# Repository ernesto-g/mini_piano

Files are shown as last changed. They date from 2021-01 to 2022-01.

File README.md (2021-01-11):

# Mini piano

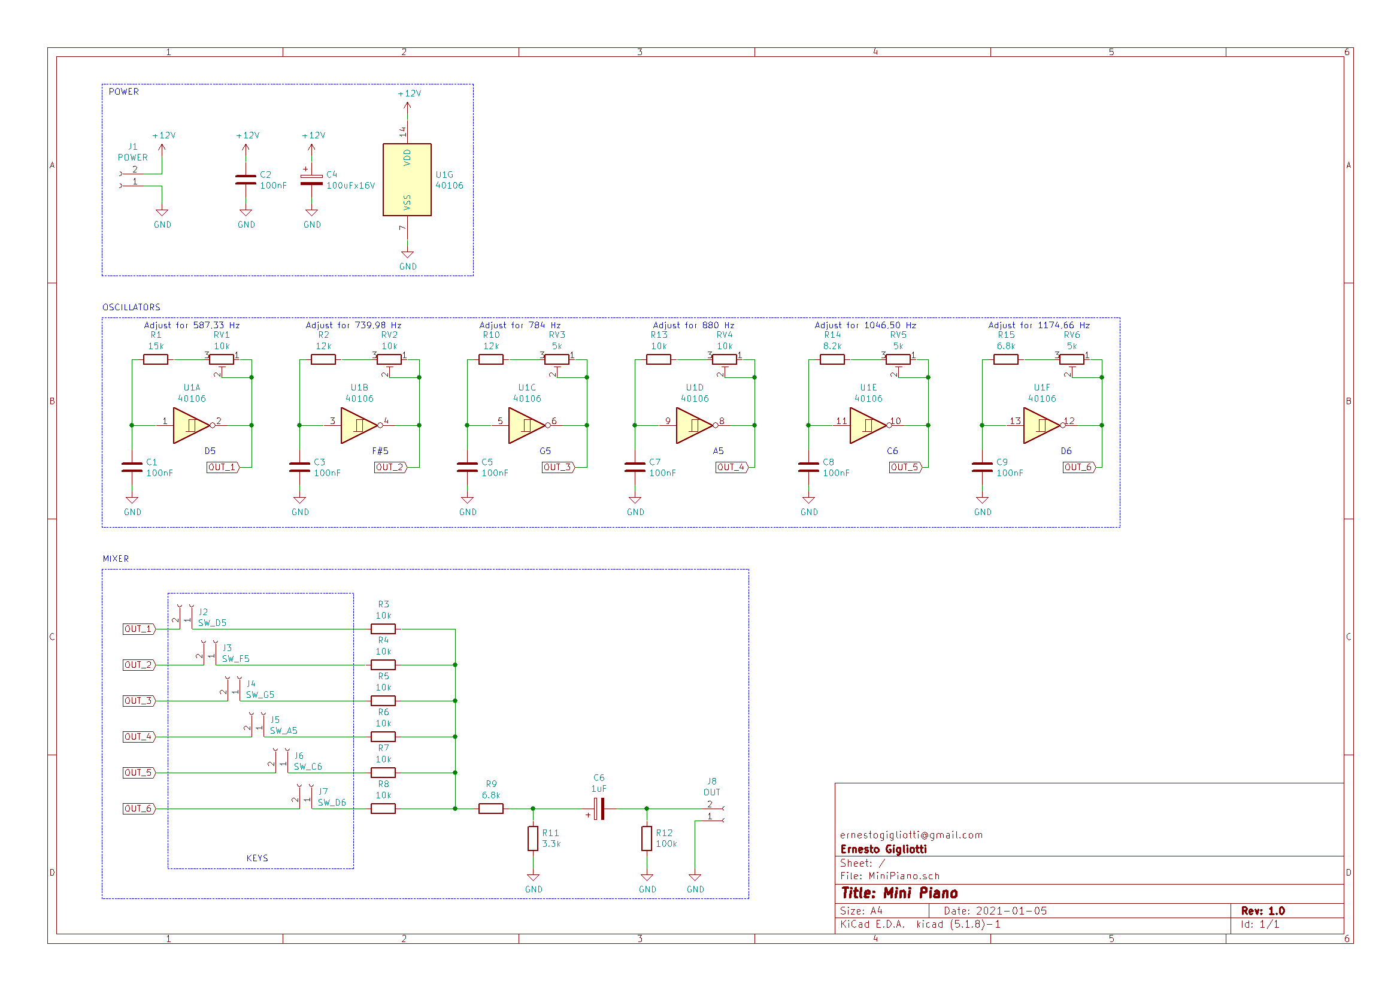
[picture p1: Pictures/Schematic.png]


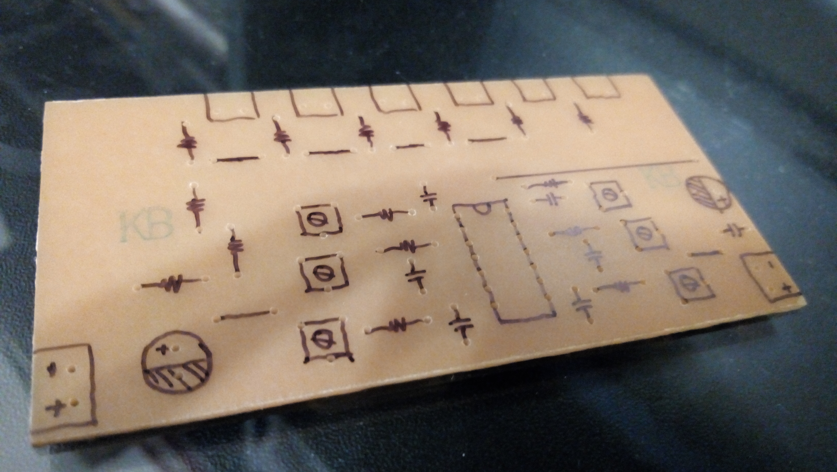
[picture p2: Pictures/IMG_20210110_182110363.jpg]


Characteristics:

  - six-note keyboard
  - D major pentatonic scale
  - 12V power input

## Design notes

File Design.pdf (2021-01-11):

Trabajo Practico: Piano con escala pentatónica

Diseñar un piano con 5 notas pertenecientes a la escala pentatónica. La forma de onda del sonido debe ser una señal cuadrada con un nivel de audio de línea. Se deberá utilizar el circuito integrado 40106 el cual consta de 6 negadores, y para la alimentación una batería de 9V.

Pasos a seguir

a) Definir las notas que tendrá el piano según la escala pentatónica y la nota raíz elegida.
b) Según la tabla de frecuencias link: https://en.wikipedia.org/wiki/Piano_key_frequencies obtener las 5 frecuencias correspondientes a las notas elegidas.
c) Plantear usar un capacitor de 1uF (1 dividido 1 millon) y calcular el valor exacto de las resistencias para los 5 casos.
d) Según los valores de R calculados, seleccionar un valor de resistencia estándar y agregarle una resistencia variable en serie para ajustar el valor de cada nota.

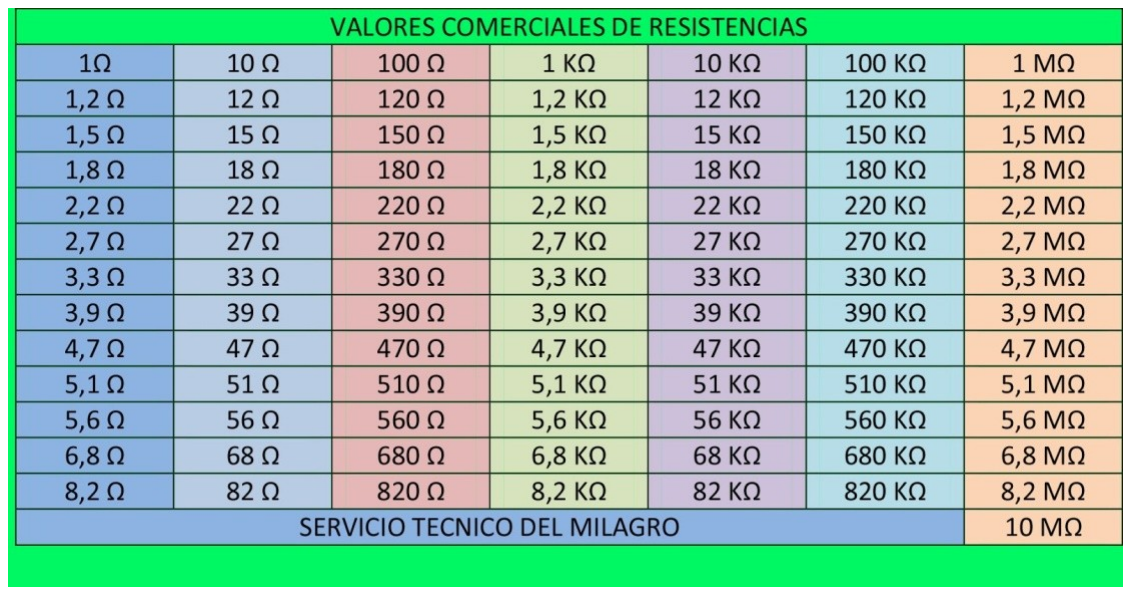
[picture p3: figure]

Los valores estándar de las resistencias variables son:

100ohm, 250ohm, 500ohm, 1K, 2.5K, 5K,10K,25K,50K,100K

e) Agregar los pulsadores (teclas) al circuito
f) Agregar circuito sumador, para poder sumar la salida de los 5 osciladores
g) Agregar el circuito para adaptar el nivel de señal a una salida de linea (1,41V )

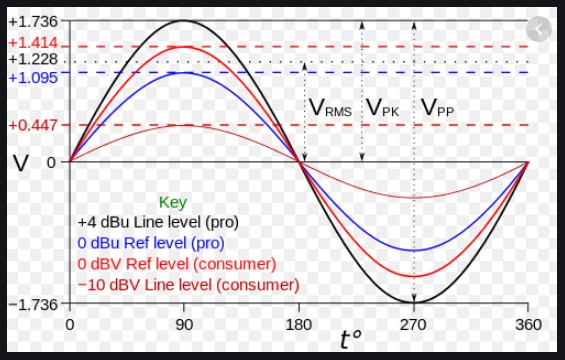
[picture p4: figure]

h) Simular circuito utilizando Proteus 8
i) Armar circuito:
1. Definir lista de componentes
2. Definir alimentación a utilizar

Resolución

1) Elección de la escala y frecuencias: Re Pentatónica
Nota | Frecuencia
D5 | 587,33 Hz
F#5 | 739,98 Hz
G5 | 784 Hz
A5 | 880 Hz
C6 | 1046,50 Hz
D6 | 1174,66 Hz
2) Calculos de resistencias suponiendo capacitor de 100nF (0,1uF)

R=

1,2
f ∗ 100 nF

RD5=

1,2
587,33Hz ∗ 100 nF

=20431,44 ohm

RF5=

1,2
739,98Hz ∗ 100 nF

=16.216,216 ohm ≈ 16 k

RG5=

1,2
784 Hz ∗ 100nF

=15306,12 ohm≈ 15k

RA 5=

1,2
880 Hz ∗ 100 nF

=13636,36 ohm≈ 14 k

RC 6=

1,2
1046,50 Hz ∗100 nF

=11466,80ohm≈ 11k

RD6=

1,2
1174,66 Hz∗100 nF

=10215,72 ohm≈ 10 k

Nota | Resistencia justa
D5 | 20K
F#5 | 16K
G5 | 15K
A5 | 14K
C6 | 11K
D6 | 10K
3) Calculamos el valor estándar de la resistencia junto a la resistencia variable para calibrar

Calculo para D5

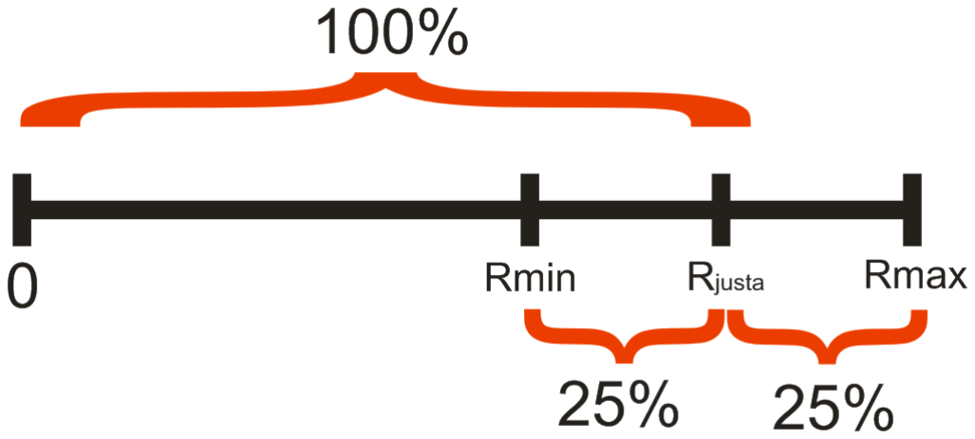
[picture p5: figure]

RD5−min=75% Rjusta=0,75∗20 K=15K

RD5−max=125 % Rjusta=1,25∗20 K=25 K

RD5−fija=RD5−min=15 k

RD5−variable=RD5−max− RD 5− min=25k −15k=10K

Calculo para F#5

RF5−min=75% Rjusta=0,75∗16 K=12K

RF5−max=125% Rjusta=1,25∗16 K=22K

RF5−fija=RF5−min=12 K

RF5−variable=RF5− max− RF5−min=22k −12 k=10 K

Calculo para G5

RG5− min=75% Rjusta=0,75∗ 15K=12K

RG5− max=125% Rjusta=1,25∗15 K=18K

RG5−fija=RG5− min=12K

RG5−variable=RG5−max−RG5−min=18 k −12 k=5 K

Calculo para A5

RA 5− min=75% Rjusta=0,75∗ 14 K=10 K

RA 5− max=125 % Rjusta=1,25∗ 14 K=18 K

RG5−fija=RG5− min=12K

RA 5−variable=RA5−max− RA5− min=18k −10 k=10 K

Calculo para C6

RC 6− min=75% Rjusta=0,75∗ 11K=8,2 K

RC 6− max=125% Rjusta=1,25∗11 K=14 K

RC 6−fija=RC 6− min=8,2K

RC 6−variable=RC6− max−RC6− min=14 k −8,2 k=5 K

Calculo para D6

RD6−min=75% Rjusta=0,75∗10 K=6,8 K

RD6−max=125 % Rjusta=1,25∗10 K=12,5 K

RD6−fija=RD6−min=6,8 K

RD6−variable=RD6− max−RD6−min=12,5 k −6,8 k=5 K

Resumen

Nota | R fija | R variable
D5 | 15K | 10K
F#5 | 12K | 10K
G5 | 12K | 5K
A5 | 10K | 10K
C6 | 8,2K | 5K
D6 | 6,8K | 5K

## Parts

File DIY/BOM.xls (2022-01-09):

Componente | Valor | Cantidad | Comentarios
> C1-C3, C5, C7-C9 | 100nF | 7
C4 | 100uFx16V | 1
C6 | 1uF | 1
J1 | POWER | 1 | PLUG HEMBRA
J2 | SW_D5 | 1
J3 | SW_F5 | 1
J4 | SW_G5 | 1
J5 | SW_A5 | 1
J6 | SW_C6 | 1
J7 | SW_D6 | 1
J8 | OUT | 1 | RCA, NO HAY JACK
R1 | 15k | 1
R2 | 12k | 1
R9 | 6.8k | 1
R10 | 18k | 1
R11 | 470 | 1
R12 | 100k | 1
> R3-R8, R13, R14 | 10k | 8
R15 | 8.2k | 1
> RV1, RV2, RV4 | 10k | 3 | NO HAY, PONEMOS 50K
> RV3, RV5, RV6 | 5k | 3
U1 | 40106 | 1
 |  |  | Si se usa RV1,RV2 y RV4 de 50K,
 |  |  | Puentear R1,R2 y R13

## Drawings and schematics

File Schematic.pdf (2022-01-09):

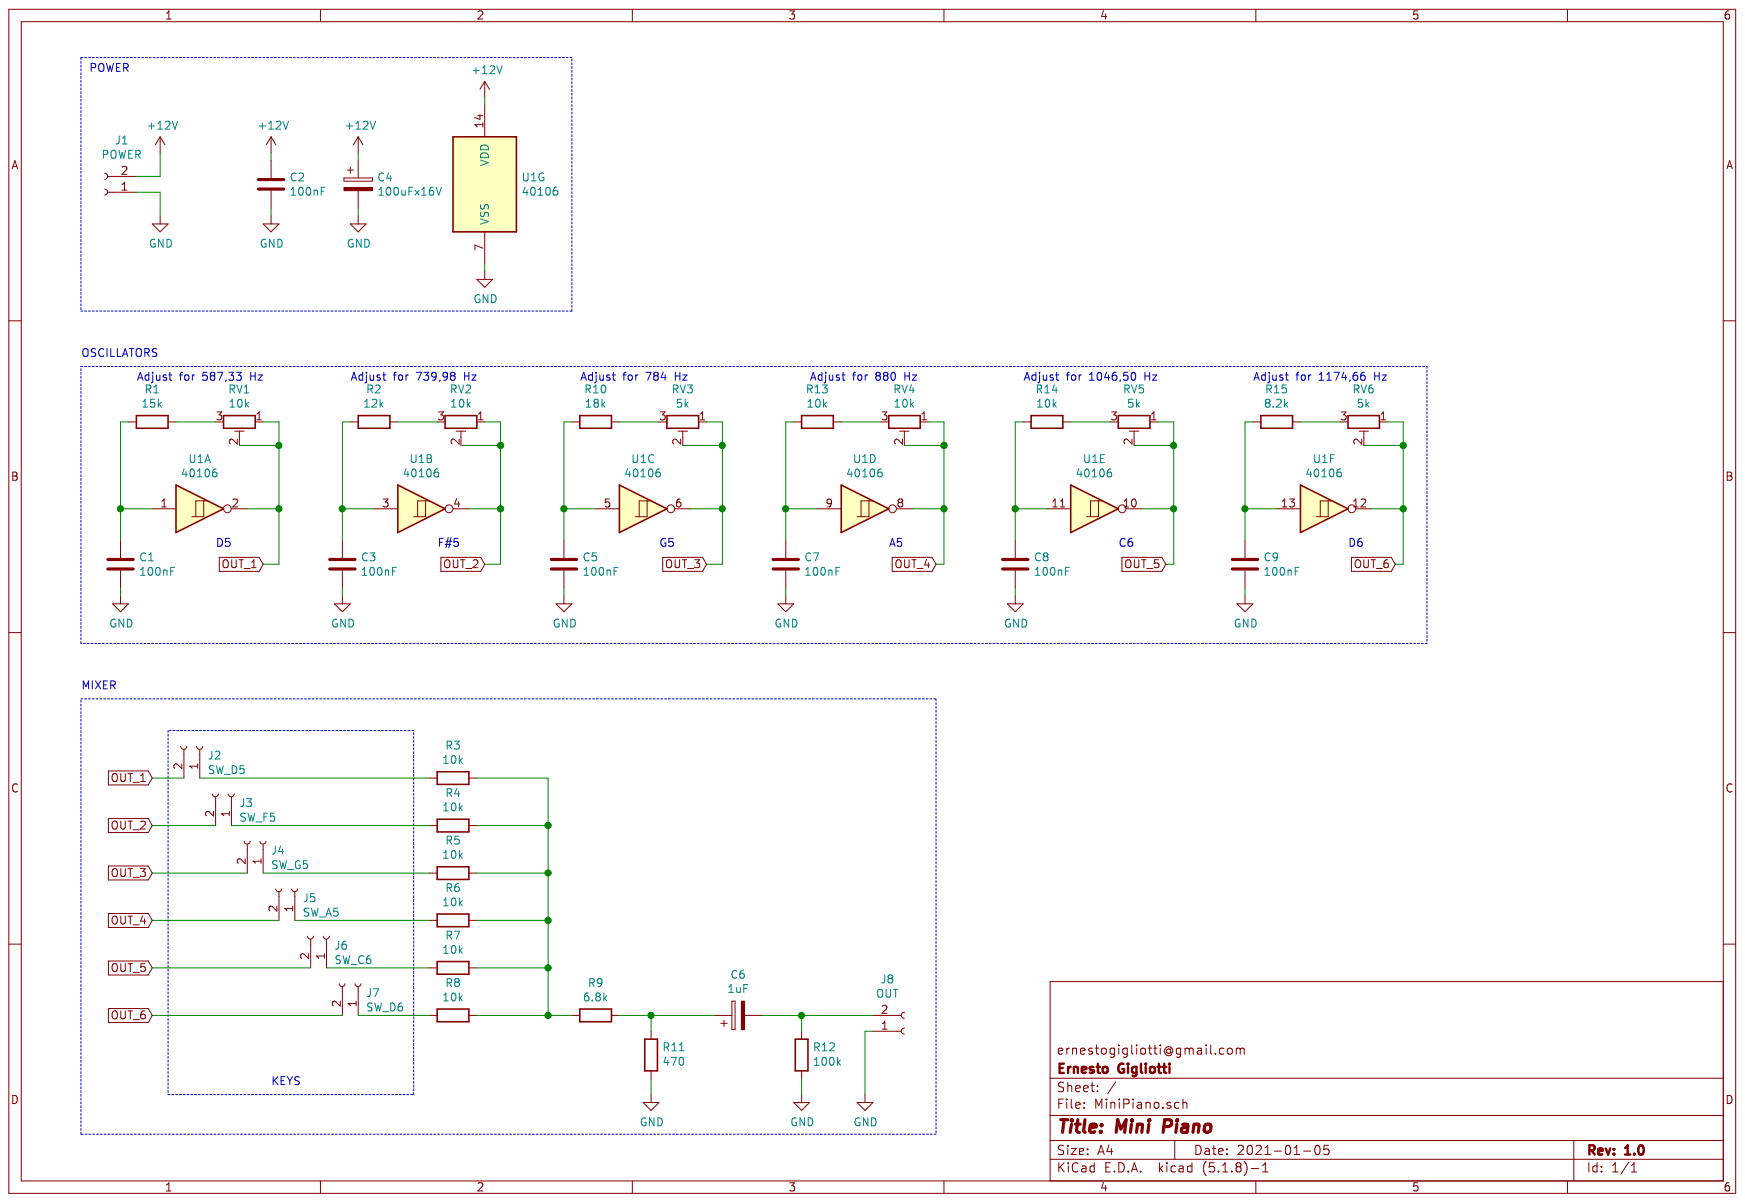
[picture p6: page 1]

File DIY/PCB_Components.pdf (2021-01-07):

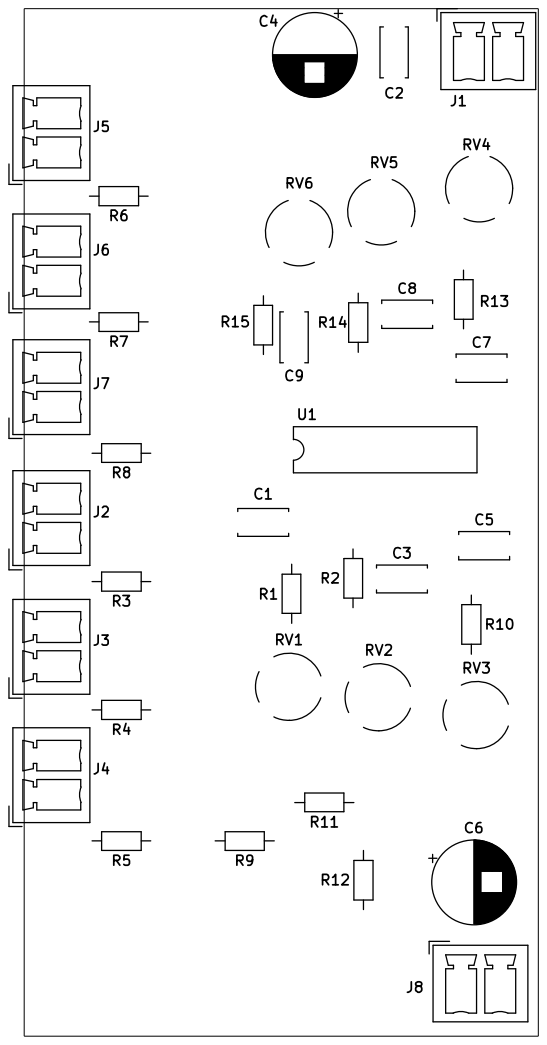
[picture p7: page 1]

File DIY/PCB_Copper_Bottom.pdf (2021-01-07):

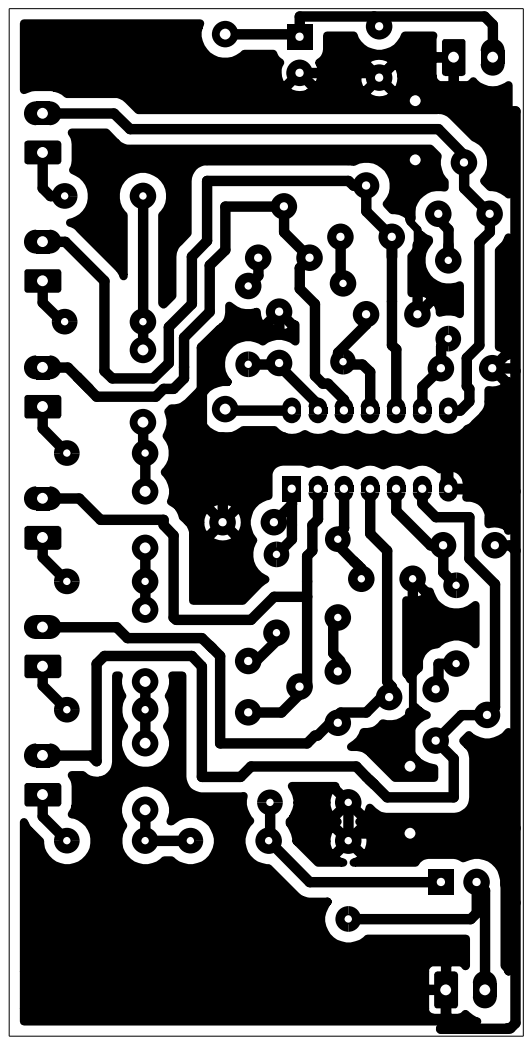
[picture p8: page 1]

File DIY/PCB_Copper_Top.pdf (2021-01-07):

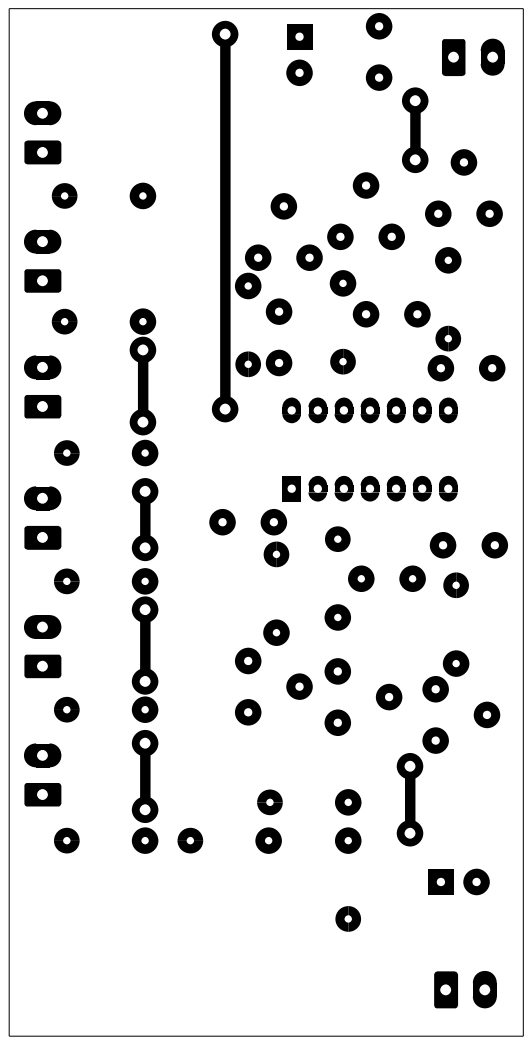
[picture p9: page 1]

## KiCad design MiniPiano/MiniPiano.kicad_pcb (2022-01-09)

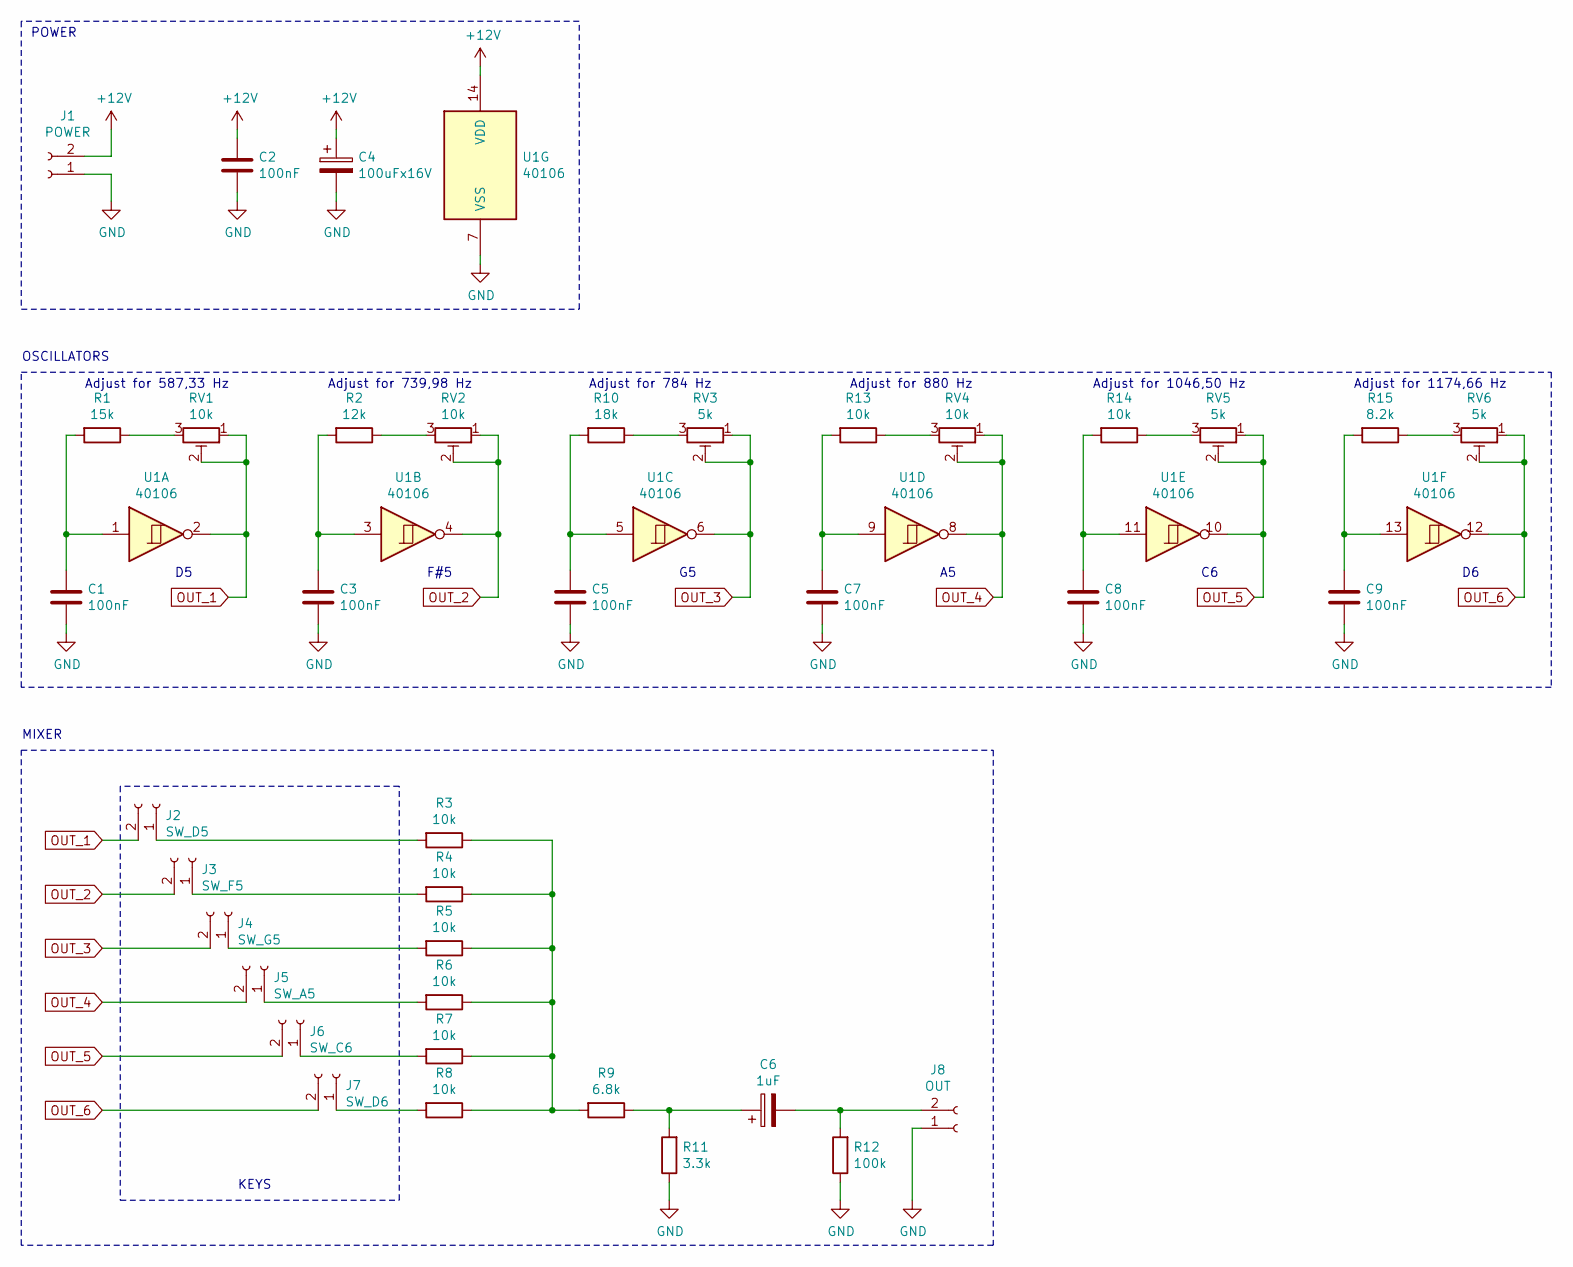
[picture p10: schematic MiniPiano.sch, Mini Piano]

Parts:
C1, C2, C3, C5, C7, C8, C9: 100nF; C_Disc_D4.7mm_W2.5mm_P5.00mm
C4: 100uFx16V; CP_Radial_D8.0mm_P3.50mm
C6: 1uF; CP_Radial_D8.0mm_P3.50mm
J1: POWER; PhoenixContact_MCV_1,5_2-G-3.81_1x02_P3.81mm_Vertical
J2: SW_D5; PhoenixContact_MCV_1,5_2-G-3.81_1x02_P3.81mm_Vertical
J3: SW_F5; PhoenixContact_MCV_1,5_2-G-3.81_1x02_P3.81mm_Vertical
J4: SW_G5; PhoenixContact_MCV_1,5_2-G-3.81_1x02_P3.81mm_Vertical
J5: SW_A5; PhoenixContact_MCV_1,5_2-G-3.81_1x02_P3.81mm_Vertical
J6: SW_C6; PhoenixContact_MCV_1,5_2-G-3.81_1x02_P3.81mm_Vertical
J7: SW_D6; PhoenixContact_MCV_1,5_2-G-3.81_1x02_P3.81mm_Vertical
J8: OUT; PhoenixContact_MCV_1,5_2-G-3.81_1x02_P3.81mm_Vertical
R1: 15k; R_Axial_DIN0204_L3.6mm_D1.6mm_P7.62mm_Horizontal
R2: 12k; R_Axial_DIN0204_L3.6mm_D1.6mm_P7.62mm_Horizontal
R3, R4, R5, R6, R7, R8, R13, R14: 10k; R_Axial_DIN0204_L3.6mm_D1.6mm_P7.62mm_Horizontal
R9: 6.8k; R_Axial_DIN0204_L3.6mm_D1.6mm_P7.62mm_Horizontal
R10: 18k; R_Axial_DIN0204_L3.6mm_D1.6mm_P7.62mm_Horizontal
R11: 3.3k; R_Axial_DIN0204_L3.6mm_D1.6mm_P7.62mm_Horizontal
R12: 100k; R_Axial_DIN0204_L3.6mm_D1.6mm_P7.62mm_Horizontal
R15: 8.2k; R_Axial_DIN0204_L3.6mm_D1.6mm_P7.62mm_Horizontal
RV1, RV2, RV4: 10k; Potentiometer_Piher_PT-6-V_Vertical
RV3, RV5, RV6: 5k; Potentiometer_Piher_PT-6-V_Vertical
U1: 40106; DIP-14_W7.62mm_LongPads

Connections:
+12V: C2.1, C4.1, J1.2, U1.14 (VDD)
GND: C1.2, C2.2, C3.2, C4.2, C5.2, C7.2, C8.2, C9.2, J1.1, J8.1, R11.1, R12.1, U1.7 (VSS)
unnamed: C1.1, R1.2, U1.1
unnamed: C3.1, R2.2, U1.3
unnamed: C5.1, R10.2, U1.5
unnamed: C6.1, R9.1, R11.2
unnamed: C6.2, J8.2, R12.2
unnamed: C7.1, R13.2, U1.9
unnamed: C8.1, R14.2, U1.11
unnamed: C9.1, R15.2, U1.13
unnamed: J2.1, R3.2
unnamed: J3.1, R4.2
unnamed: J4.1, R5.2
unnamed: J5.1, R6.2
unnamed: J6.1, R7.2
unnamed: J7.1, R8.2
unnamed: R1.1, RV1.3
unnamed: R2.1, RV2.3
unnamed: R3.1, R4.1, R5.1, R6.1, R7.1, R8.1, R9.2
unnamed: R10.1, RV3.3
unnamed: R13.1, RV4.3
unnamed: R14.1, RV5.3
unnamed: R15.1, RV6.3
OUT_1: J2.2, RV1.1, RV1.2, U1.2
OUT_2: J3.2, RV2.1, RV2.2, U1.4
OUT_3: J4.2, RV3.1, RV3.2, U1.6
OUT_4: J5.2, RV4.1, RV4.2, U1.8
OUT_5: J6.2, RV5.1, RV5.2, U1.10
OUT_6: J7.2, RV6.1, RV6.2, U1.12

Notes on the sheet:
POWER
OSCILLATORS
F#5
MIXER
KEYS
Adjust for 587,33 Hz
Adjust for 739,98 Hz
Adjust for 784 Hz
Adjust for 880 Hz
Adjust for 1046,50 Hz
Adjust for 1174,66 Hz

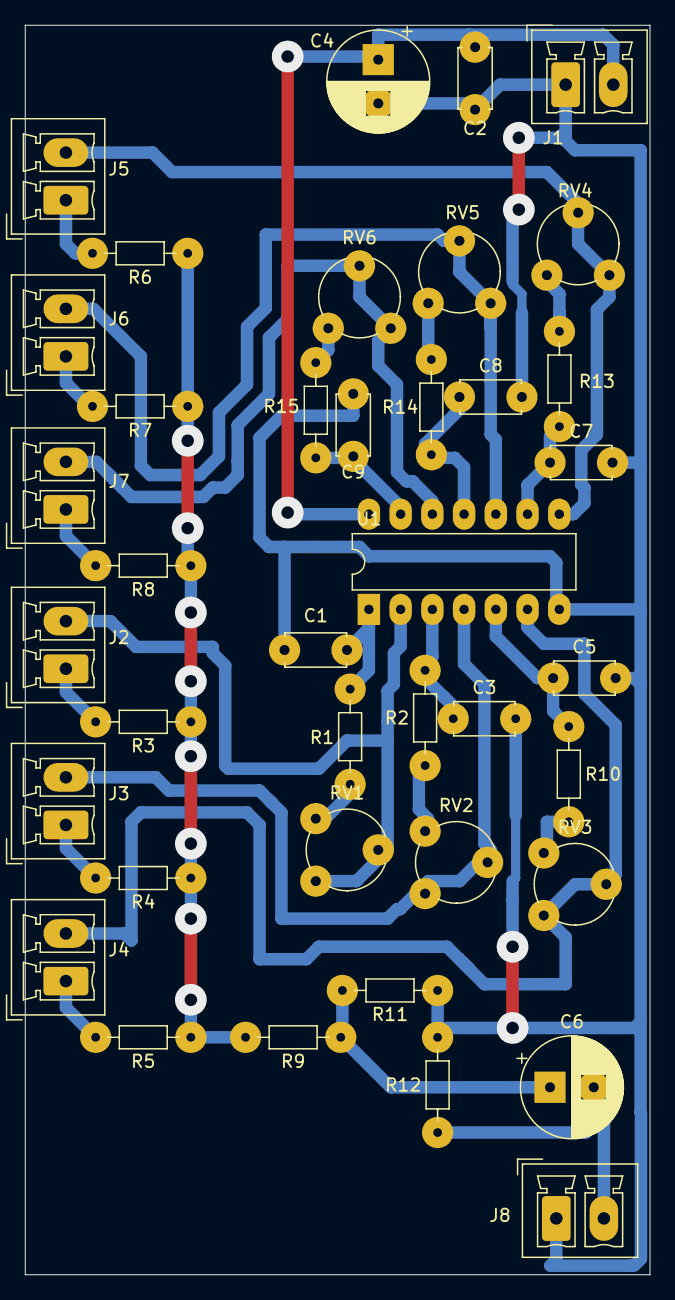
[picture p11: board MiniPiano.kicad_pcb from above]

Board: 2 copper layers, 50.0 x 100.0 mm, 39 parts (0 on the bottom side), 29 nets.

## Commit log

2022-01-09 fix valores de resistencias
    [BOM.xls, MiniPiano.kicad_pcb, MiniPiano.sch]
2022-01-09 fix resistencias
    [BOM.xls, MiniPiano.sch]
